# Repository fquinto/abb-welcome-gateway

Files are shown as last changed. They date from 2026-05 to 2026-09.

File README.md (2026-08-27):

# abb-welcome-gateway

ESP32-S3 gateway that connects an **ABB-Welcome / Busch-Welcome** 2-wire door
intercom to **Home Assistant**: doorbell notifications, remote door opening and
diagnostics, powered directly from the intercom bus.

| Top | Bottom |
|---|---|
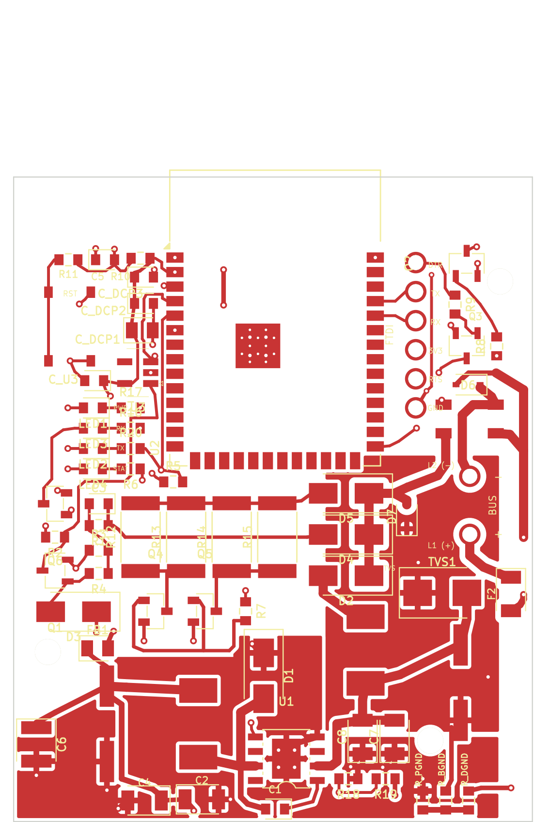
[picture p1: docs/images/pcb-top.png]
PCB top
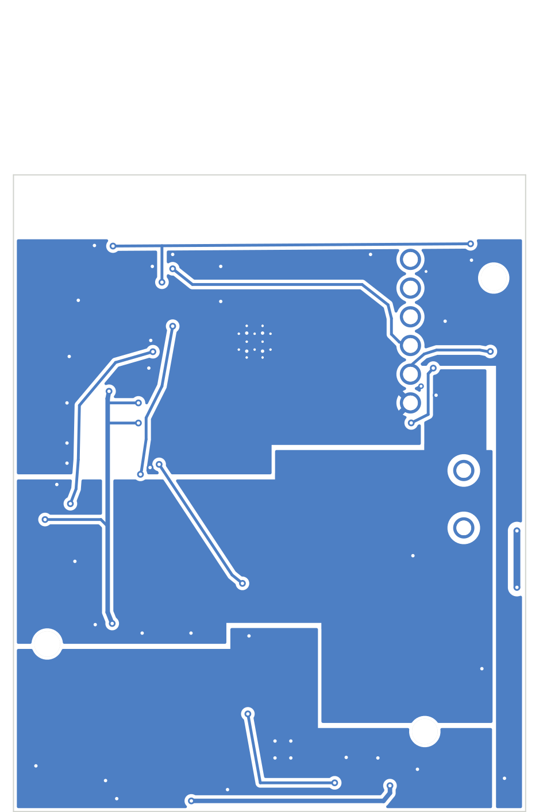
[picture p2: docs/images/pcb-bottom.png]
PCB bottom
|  |  |

## Highlights

- **Bus-powered**: TPS5430 buck converter runs the board from the ~28 V bus.
- **ESP32-S3-WROOM-1** with the antenna at the board edge and a proper copper
  keep-out.
- **Clean bus front-end**: filtered tap, TVS + reverse-polarity protection,
  polyfuse, Schmitt-buffered RX and open-drain TX drivers.
- **Three separated ground islands** (power / digital / bus) stitched at a
  single star point, so switching and RF return currents stay out of the bus
  reference.
- **ESPHome firmware**: native Home Assistant integration, OTA updates,
  YAML-only configuration for the end user.

## Repository layout

| Path | Contents |
|---|---|
| [`hardware/kicad-v3/`](hardware/kicad-v3/) | **The board** (KiCad 9): fully routed 2-layer PCB, DRC-clean. Source of truth for the hardware. |
| [`firmware/esphome/`](firmware/esphome/) | ESPHome configuration + `abb_welcome` custom component. |
| [`docs/`](docs/) | [Status](docs/STATUS.md) · [Pending tasks](docs/TODO.md) · [User guide](docs/user-guide.md). |
| [`legacy/`](legacy/) | Frozen design history: original EasyEDA v2 design, the tscircuit schematic capture of v3 and the conversion tooling. |

## Status

- **Hardware**: v3.0 design finished and fully routed; pre-fabrication
  verification pending (details in [docs/STATUS.md](docs/STATUS.md)).
- **Firmware**: ESPHome skeleton in place; ABB-Welcome bus protocol in
  development ([docs/TODO.md](docs/TODO.md)).

## Getting started

See the [user guide](docs/user-guide.md) for wiring, first flash over the
FTDI header and Home Assistant setup.

For hardware development: open `hardware/kicad-v3/abb-welcome-gateway-v3.kicad_pro`
in KiCad 9. Design rules, net classes and the ground-island scheme are described
in [`hardware/kicad-v3/README.md`](hardware/kicad-v3/README.md).

## Community & discussion

Questions, ideas or want to share your build? Join the discussion on Telegram:



## Donations for software development

If this project is useful to you, you can support its development:



Thank you for collaborating and helping the development of software improvements.

## Credits & license

The hardware derives from the original bus interface design by **mat931**.
Hardware is licensed under **CERN-OHL-W v2** (see [`LICENSE`](LICENSE));
the full design history is preserved in [`legacy/`](legacy/) and in the git log.

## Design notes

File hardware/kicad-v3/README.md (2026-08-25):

# KiCad v3 — routing target

KiCad project exported from the tscircuit v3 design (`legacy/tscircuit/index.circuit.tsx`)
so the board can be **routed in KiCad** (tscircuit's autorouter does not converge
on this board and produces no copper pours, which this design needs — three GND
islands, an RF module, the buck power stage and the 28 V bus all want planes /
poured copper, not point-to-point traces).

## Files

- `abb-welcome-gateway-v3.kicad_pro` — project (open this in KiCad).
- `abb-welcome-gateway-v3.kicad_pcb` — board: **fully routed** (traces, vias,
  the three GND island pours and stitching). `kicad-cli pcb drc`: 0 errors,
  0 unconnected items.
- `abb-welcome-gateway-v3.kicad_sch` — schematic.

Generated with `circuit-json-to-kicad` (KiCad file format `20241229`, i.e. KiCad 8/9).

## Source-of-truth note

Routing has started (and finished) here, so **this KiCad project is now the
source of truth for the PCB**. The tscircuit side (`legacy/tscircuit/index.circuit.tsx`)
is frozen as schematic reference; it does NOT reflect the physical changes below.

### Divergences from the tscircuit source (v3.0 routed)

- **U2 footprint replaced**: the tscircuit wrapper's hand-made 61-pad QFN-style
  footprint is not the real module. U2 now uses KiCad's official
  `RF_Module:ESP32-S3-WROOM-1` (41 pads + EP), antenna flush with the top board
  edge, with its copper keep-out.
- **LED_PIN moved from GPIO2 to GPIO6** (module pin 38 -> pin 6): the status
  LED net could not be routed out of the P2/FTDI quadrant. **Firmware must
  drive the status LED on GPIO6, not GPIO2.**
- **Board grown to 45.4 x 56.4 mm** (+3 mm height) to fit the buck band.
- Placement reworked by ground island (DGND top / BUS_GND middle+bus entry /
  PGND bottom): U1 rotated 180 (VIN toward C7/C8, SW toward D1/L2), feedback
  divider at the FB pin, star point (R_PGND/R_BGND/R_DGND) bottom-right,
  C4/C6 moved into the PGND island, LEDs rotated 180 (cathodes west), R5 and
  R8 relocated, TVS1 next to C23.
- Several nets use short B.Cu jogs; the DGND plane keeps deliberate bridges
  (module strip, east region) — re-run the zone fill after any edit.

## Regenerating (before any manual routing)

The export is driven by `@tscircuit/eval` → `circuit-json-to-kicad`. On a machine
where the tscircuit CLI runs (it needs the platform-native `@resvg/resvg-js`
binary), the supported one-liner is:

```bash
cd output
npx tsci export -f kicad_pcb index.circuit.tsx     # or: -f kicad_zip for the whole project
```

(These files were produced via the library path because the CLI's resvg binary
wasn't available in the generating environment; `tsci export` is the canonical way.)

## Routing checklist for this board

- Pour **separate ground regions** for `PGND` / `DGND` / `BUS_GND`; tie them only at
  the star point via R_PGND / R_DGND / R_BGND (the 0 Ω links).
- Keep the ESP32-S3 **antenna keep-out** clear (no copper under/near the antenna).
- Wide traces / short loops on the **buck power stage** (BUS_PWR, SW_NODE, PGND, L2, C2).
- **HV clearance** on the 28 V bus front-end (P1, F2, L1, D2/D4/D5/D7, TVS1).

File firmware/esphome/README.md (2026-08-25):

# Firmware (ESPHome)

- `abb-welcome-gateway.yaml` — device configuration. Copy
  `secrets.yaml.example` to `secrets.yaml`, fill in your credentials, edit the
  `substitutions` (bus addresses) and the door-open `data` payload for your
  installation, then run `esphome run abb-welcome-gateway.yaml`.

## How it works

The ABB-Welcome / Busch-Welcome protocol is implemented natively by ESPHome
(the `abbwelcome` remote protocol in `remote_base`, since 2024.4.0), so this
project needs **no custom protocol code**:

- `remote_receiver` on GPIO4 with `dump: [abbwelcome]` decodes bus frames; the
  `on_abbwelcome` automation fires the doorbell `binary_sensor` on a call.
- `remote_transmitter` on GPIO5 sends the door-open frame via
  `remote_transmitter.transmit_abbwelcome`.
- The status LED (GPIO6) is driven by ESPHome's `status_led` component.

See [`../../docs/protocol.md`](../../docs/protocol.md) for the protocol and
[`../../docs/user-guide.md`](../../docs/user-guide.md) for discovering your
addresses and the door-opener secret.

## To confirm on hardware

The RX front-end ends in a Schmitt inverter (74LVC1G14) and TX is open-drain,
so the net logic polarity is not certain from the schematic. If frames don't
decode or the door doesn't open, try `inverted: true` on the receiver and/or
transmitter pin. Tracked in [`../../docs/TODO.md`](../../docs/TODO.md).

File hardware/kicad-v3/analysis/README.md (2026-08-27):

# Pre-fabrication analysis

Numerical checks for the two open items in
[`docs/STATUS.md`](../../../docs/STATUS.md) → *To verify before fabrication*:

1. **Buck control loop** with `L2 = 100 µH` and ~590 µF of bulk — is it stable
   and fast enough?
2. **TVS1 (SMBJ30A) clamp** versus the TPS5430's 36 V VIN absolute maximum.

These are **models to guide the bench measurement, not a replacement for it.**
Absolute phase-margin numbers carry roughly ±15° of modelling/tolerance
uncertainty; the *trends* are what matter.

## Run

```sh
python3 buck_loop_analysis.py   # prints margins table + writes tps5430_bode.png
python3 tvs_clamp.py            # prints TVS clamp vs surge current
```

Requires `numpy`, `scipy`, `matplotlib`.

---

## 1. Buck loop stability

**Model.** The TPS5430 is a voltage-mode buck with a *fixed internal type-III*
compensation network whose transfer function is published in the datasheet
(SLVS632, Eq. 15): zeros at 2170 / 2590 Hz, poles at 2165 Hz (integrator),
24 k, 54 k, 440 kHz. We combine it with the power stage built from the **real
output-cap network** (C19 470 µF Al, C6 100 µF Ta, C2/C4 10 µF Ta — each as
`ESR + 1/sC` in parallel) and calibrate the one unknown constant (the
feed-forward modulator gain `VIN/Vramp`) so the datasheet's own worked example
(5 V, 15 µH, 220 µF, 40 mΩ) crosses 0 dB at 18 kHz. Calibrated value ≈ **22.9**,
which is physically sensible for this part.

**Result (nominal, C19 ESR = 0.10 Ω, 0.3 A load):**

| Metric | Value |
|---|---|
| Crossover `fCO` | **≈ 3.2 kHz** |
| Phase margin | **≈ 70°** |
| Gain margin | **≈ 36 dB** |
| Load-step 0.3 A | ~27 mV dip, ~0.6 ms recovery |

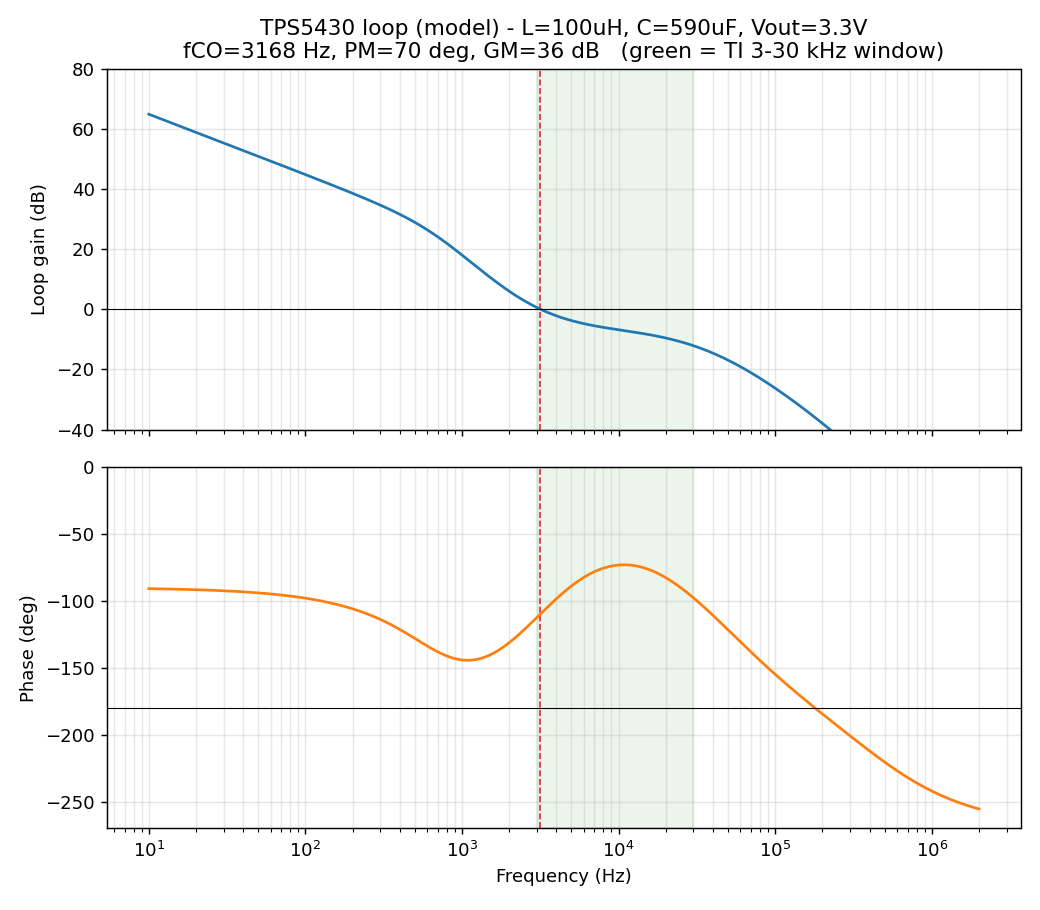
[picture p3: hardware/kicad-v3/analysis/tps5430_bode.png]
Bode plot


**Why this refines the STATUS.md note.** The note estimated `fCO ≈ 1.5 kHz`
(from TI's Eq. 7, `fLC²/85·VOUT`) and worried it sat *below* TI's 3–30 kHz
window — sluggish and marginal. Eq. 7 is **pessimistic here because it assumes a
low-ESR output cap**. In reality the aluminium electrolytic's ESR zero
(≈ 3.4 kHz) sits inside the loop, lifts the gain and, together with the internal
type-III zeros at 2.2 / 2.6 kHz, pushes the crossover **up to ~3.2 kHz — the
bottom edge of TI's window — with a healthy ~70° phase margin.** The note's
instinct ("stable thanks to the ESR") is correct; the "marginal" part is not.

**Robustness.** Stable across the whole plausible electrolytic ESR range and load:

| C19 ESR (Ω) | 0.05 | 0.08 | 0.10 | 0.12 | 0.15 | 0.20 |
|---|---|---|---|---|---|---|
| Phase margin | 48° | 62° | 70° | 79° | 90° | 106° |

Phase margin *increases* with ESR, and the worst case (fresh/warm cap, ESR ≈
0.05 Ω) still gives ~48°. Load current 0.1–2 A holds ~70°. So the design is
comfortably stable in the model.

**Confirmed warning — do NOT swap the bulk for low-ESR ceramics.** Removing the
ESR zero collapses the phase margin from ~70° to **~19°** (ringy / marginal):

| Output bulk | fCO | Phase margin |
|---|---|---|
| 590 µF electrolytic/Ta (as designed) | 3.2 kHz | **70°** |
| 590 µF low-ESR ceramic | 2.6 kHz | **19°** ⚠ |

Keep C19/C6/C2/C4 as specified, or add an external compensation network first.

**Bench check on the first board:** loop is *predicted* fine, but the crossover
is set by the electrolytic ESR (drifts with temperature/age). Confirm with a
load-step (look for clean recovery ~0.5 ms, no sustained ringing) or, better, an
injected-signal Bode. Expect crossover ~3 kHz and no gain peaking.

---

## 2. TVS1 clamp vs buck VIN abs-max

**Model.** Piecewise-linear TVS, `Vclamp(I) = VBR + I·Rdyn`. SMBJ30A datasheet
points: `VWM = 30 V`, `VBR(min) = 33.3 V`, `VC = 48.4 V @ IPP = 12.4 A`
→ `Rdyn ≈ 1.22 Ω`.

| TVS current | Clamp voltage | vs 36 V abs-max |
|---|---|---|
| 0.5 A | 33.9 V | OK |
| 1 A | 34.5 V | OK |
| **2.2 A** | **36.0 V** | = abs-max |
| 5 A | 39.4 V | over |
| 12.4 A | 48.4 V | over |

**Reading.** At the 28 V bus nominal the 30 V standoff means no conduction, and
clamping only starts above ~33 V — good. The buck's 36 V abs-max is exceeded
only once the TVS conducts **more than ~2.2 A**. Two mitigations decide whether
that matters:

- **Fast transients (ESD / inductive spikes): covered.** `L3 = 100 µH` in
  series plus the input caps isolate the buck VIN node — the buck never sees the
  fast edge, so the clamp voltage at the bus side is not what reaches it.
- **Slow, sustained high-current overvoltage: residual gap.** L3 has no
  impedance at DC, so a slow fault that drives >2.2 A into the TVS can pull the
  buck VIN above 36 V while the TVS clamps at up to 48 V.

For a 28 V low-voltage intercom bus a high-energy surge is unlikely, so the
practical risk is low. For guaranteed protection (belt-and-suspenders):

- **Relocate TVS1 to the buck VIN node (downstream of L3)** — near-free board
  revision, clamps the node the buck actually sees; or
- use a **40–60 V-rated buck** (e.g. TPS54360, LMR14030) for unconditional VIN
  headroom.

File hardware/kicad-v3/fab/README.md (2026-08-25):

# Fabrication outputs

Generated from `abb-welcome-gateway-v3.kicad_pcb` with `kicad-cli` (KiCad 9).
Regenerate with the commands at the bottom after any board change.

## Files

| File | Purpose |
|---|---|
| `abb-welcome-gateway-v3-gerbers.zip` | Gerbers (RS-274X) + Excellon drill — upload this to the fab house. |
| `gerbers/` | The individual layers, unzipped. |
| `abb-welcome-gateway-v3-BOM.csv` | Bill of materials (grouped). |
| `abb-welcome-gateway-v3-pos.csv` | Pick-and-place / centroid (both sides, drill-file origin). |

## Board parameters

- **Layers**: 2 (signal + poured grounds).
- **Size**: 45.4 × 56.4 mm.
- **Min track / clearance**: 0.2 mm. **Min via**: 0.6 mm / 0.3 mm drill.
- **Copper**: 1 oz suggested. Finish HASL or ENIG (ENIG preferred for the
  fine-pitch module and the QFN-style TPS5430 thermal pad).
- All components are on the **top** side; the bottom is ground pours only.

## BOM notes

- The `LCSC` column carries the part numbers defined in the design. Entries left
  blank are **generic passives** (0603 resistors/capacitors, the ferrite bead,
  the FTDI header) — assign an LCSC basic part by value + package in the
  assembly tool. They are intentionally not guessed here to avoid fitting the
  wrong part.
- **Through-hole parts** (`P1` screw terminal, `P2` FTDI header) are not covered
  by standard SMT assembly — hand-solder them or request THT assembly.
- Three tooling/mounting holes are NPTH (no BOM line).

## Regenerating

```bash
cd hardware/kicad-v3
PCB=abb-welcome-gateway-v3.kicad_pcb

kicad-cli pcb export gerbers --output fab/gerbers/ \
  --layers "F.Cu,B.Cu,F.Paste,B.Paste,F.SilkS,B.SilkS,F.Mask,B.Mask,Edge.Cuts" \
  --no-protel-ext "$PCB"
kicad-cli pcb export drill --output fab/gerbers/ --format excellon \
  --drill-origin absolute --excellon-units mm --generate-map --map-format gerberx2 "$PCB"
kicad-cli pcb export pos --output fab/abb-welcome-gateway-v3-pos.csv \
  --format csv --units mm --side both --use-drill-file-origin "$PCB"
( cd fab && zip -j abb-welcome-gateway-v3-gerbers.zip gerbers/*.gbr gerbers/*.drl gerbers/*.gbrjob )
```

The BOM is built by `tools`-free script logic (see the project history); for a
quick refresh from the schematic instead:
`kicad-cli sch export bom --group-by Value --output fab/BOM.csv abb-welcome-gateway-v3.kicad_sch`.

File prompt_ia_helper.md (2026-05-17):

Always create tscircuit code inside of an HTML canvas (use a tool)

Do not import any components! Just use the builtin tscircuit elements (described below)

Make sure to create a script tag with from the source "https://unpkg.com/@tscircuit/circuit-preview@latest/dist/index.global.js" and a script tag with type="text/babel" that contains the window.tscircuit.render function call.

<html>
  <head>
    <script src="https://unpkg.com/@tscircuit/circuit-preview@latest/dist/index.global.js"></script>
    <script type="text/babel">
      window.tscircuit.render(
        <board pcbPack>
          <chip
            name="U1"
            footprint="soic8"
            pinLabels={{
              pin1: "GND",
              pin2: "TRIG",
              pin3: "OUT",
              pin4: "RESET",
              pin5: "CTRL",
              pin6: "THRES",
              pin7: "DISCH",
              pin8: "VCC",
            }}
            schPinArrangement={{
              leftSide:  { direction: "top-to-bottom", pins: ["RESET","CTRL","THRES","TRIG"] },
              rightSide: { direction: "top-to-bottom", pins: ["VCC","OUT","DISCH","GND"] },
            }}
          />
          <resistor  name="R1" resistance="1k"    footprint="0805" />
          <resistor  name="R2" resistance="10k"   footprint="0805" />
          <capacitor name="C1" capacitance="10uF" footprint="1206" />
          <capacitor name="C2" capacitance="0.01uF" footprint="0805" />
          <led       name="D1" color="red" footprint="led0603" />
          <resistor  name="R3" resistance="330" footprint="0805" />
          <trace from="U1.VCC"   to="net.VCC" />
          <trace from="U1.GND"   to="net.GND" />
          <trace from="U1.RESET" to="net.VCC" />
          <trace from="U1.CTRL"  to="C2.pin1" />
          <trace from="C2.pin2"  to="net.GND" />
          <trace from="U1.THRES" to="U1.TRIG" />
          <trace from="net.VCC"  to="R1.pin1" />
          <trace from="R1.pin2"  to="U1.DISCH" />
          <trace from="U1.DISCH" to="R2.pin1" />
          <trace from="R2.pin2"  to="U1.THRES" />
          <trace from="U1.THRES" to="C1.pin1" />
          <trace from="C1.pin2"  to="net.GND" />
          <trace from="U1.OUT"   to="R3.pin1" />
          <trace from="R3.pin2"  to="D1.pin1" />
          <trace from="D1.pin2"  to="net.GND" />
        </board>
      )
    </script>
  </head>
  <body></body>
</html>

Here's a quick primer on how to use tscircuit:

## Core `<chip />` props (most-used)

* `name`: reference designator (e.g., `"U1"`).
* `footprint`: **string** (e.g., `"soic8"`/`"0402"`) **or** a `<footprint />` element.
* `pinLabels`: map pad → pin label (e.g., `{ pin1: "VCC", pin5: "GND" }`).
* `schPinArrangement`: control schematic sides/order of pins (alias **`schPortArrangement`** is deprecated).
  Optional styling/box props: `schPinStyle`, `schPinSpacing`, `schWidth`, `schHeight`. ([GitHub][3])
* Connectivity helpers:
  `internallyConnectedPins`, `externallyConnectedPins`, and **`connections`** (auto‑traces by pin label)
* Extras: `pcbPinLabels`, `cadModel`, `noSchematicRepresentation`

---

## Minimal chip

<chip
  name="U1"
  footprint="soic8"
  pinLabels={{ pin1: "VCC", pin2: "DISCH", pin3: "THRES", pin4: "CTRL",
               pin5: "GND", pin6: "TRIG", pin7: "OUT", pin8: "RESET" }}
/>

## Arrange pins on schematic (+ style/size)

<chip
  name="U1" footprint="soic8" pinLabels={{ pin1:"VCC", pin5:"GND", pin7:"OUT", pin8:"RESET" }}
  schPinArrangement={{
    leftSide:  { direction: "top-to-bottom",    pins: ["VCC"] },
    rightSide: { direction: "bottom-to-top",    pins: ["GND","OUT","RESET"] },
    topSide:   { direction: "left-to-right",    pins: [] },
    bottomSide:{ direction: "left-to-right",    pins: [] },
  }}
  schPinStyle={{ GND: { topMargin: "0.5mm" } }}
  schPinSpacing={0.75} schWidth="12mm"
/>

## Custom PCB footprint (inline)

<chip
  name="U1"
  footprint={
    <footprint>
      <smtpad portHints={["1"]} pcbX="-1mm" pcbY="0" width="1mm" height="0.7mm" />
      <smtpad portHints={["2"]} pcbX="1mm"  pcbY="0" width="1mm" height="0.7mm" />
    </footprint>
  }
/>

## Internally / externally shorted pins

<chip
  name="SW1" footprint="pushbutton"
  internallyConnectedPins={[["pin1","pin4"],["pin2","pin3"]]}
/>

<chip
  name="U1" footprint="soic8" pinLabels={{ pin1:"VCC", pin5:"GND", pin6:"TRIG", pin2:"DISCH" }}
  externallyConnectedPins={[["GND","DISCH"],["TRIG","VCC"]]}
/>

## Auto‑connect with `connections`

A more condensed alternative to `<trace />`, available on basically all elements

<chip
  name="U1" footprint="soic8" pinLabels={{ pin1:"VCC", pin5:"GND", pin7:"OUT" }}
  connections={{ VCC: "net.V5", GND: "net.GND", OUT: "net.SIGNAL" }}
/>

Use with `sel` for type‑safe selectors (e.g., `OUT: sel.U2(MyReg).VOUT`). ([GitHub][3], [docs.tscircuit.com][4])

## Part selection & PCB labels

<chip
  name="U1" footprint="soic8"
  supplierPartNumbers={{ jlcpcb: ["C57759"] }}
  manufacturerPartNumber="SN74HC14DR"
  pcbPinLabels={{ "1":"TX", "2":"RX" }}
/>

## All normal elements and important props

Most elements have a `name` and `footprint` prop. Most properties
are optional.

- `<board />` - root element
- `<group />` - group of elements
- `<chip name="U1" pinLabels={{ pin1: "VCC", ... }} />` - any generic chip
- `<resistor name="R1" resistance="1k" footprint="0402" />` - `resistance`
- `<capacitor name="C1" capacitance="100n" footprint="0402" />` - `capacitance`
- `<inductor name="L1" inductance="100n" footprint="0402" />` - `inductance`
- `<led name="LED1" color="red" />` - `color`
- `<diode name="D1" variant="standard" />` - `variant` (standard/schottky/zener/avalanche/photo/tvs)
- `<trace from="U1.VCC" to="R1.pin1" />` - `from`, `to`
- `<transistor name="Q1" type="npn" />` - `type` (npn/pnp/nmos/pmos)
- `<mosfet name="M1" channelType="n" mosfetMode="enhancement" />` - `channelType` (n/p), `mosfetMode` (enhancement/depletion)
- `<hole name="H1" diameter="1mm" />` - `diameter`
- `<testpoint name="TP1" />` - `padShape` (circle/rect), `padDiameter`, `footprintVariant` (smd/through_hole), `width`, `height`
- `<via />` - `holeDiameter`, `outerDiameter`
- `<switch />` - `spdt` (bool), `dpdt` (bool), `spst` (bool), `spdt` (bool), `isNormallyClosed`
- `<pinheader />` - `pinCount`, `schFacingDirection` (left, up, right, down), `schPinArrangement`, `gender` (male/female/unpopulated), `showSilkscreenPinLabels`, `holeDiameter`, `connections`, `pinLabels`, `rightAngle`, `doubleRow`
- `<jumper name="J1" pinCount={2} pinLabels={{ pin1: "A", pin2: "B" }} />` - similar to pinheader but pin count must be 2 or 3
- `<fuse name="F1" currentRating="1A" voltageRating="250V" />`
- `<pushbutton name="SW1" />`
- `<cutout shape="rect" width="1mm" height="1mm" />` - `shape` (rect), `width`, `height`
- `<crystal name="X1" frequency="10MHz" />` - `frequency`, `loadCapacitance`, `loadResistance`
- `<battery name="BAT1" />` - `capacity`, `voltage`
- `<potentiometer name="P1" maxResistance="10k" pinVariant="two_pin" />` - `maxResistance`, `pinVariant` (two_pin/three_pin). Common footprint "pinrow2"/"pinrow3"

### Footprint Only Elements

- `<smtpad />` - `portHints`, `pcbX`, `pcbY`, `shape`, `width`, `height`
- `<platedhole />` - `pcbX`, `pcbY`, `shape`, `width`, `height`

## Common Footprints

- "0402", "0603", "0805", "1206", "1210"
- "dip", "dip8", "dip16", "axial", "soic8", "bga64", "tssop8", "stampboard", "stampreceiver", "hc49", "to92", "to220", "ssop", "qfp16", "qfn16", "sot23", "sot23_5", "sot223", "pinrow2", "pinrow6"
- You can generally alter footprints by changing numbers or adding parameters e.g. "soic8_w4mm" creates a 4mm width soic, "pinrow8_p1mm" creates an 8 pin pinrow with 1mm pitch
- For batteries, just use "pinrow2"

## Selector Syntax

When specifying a selector, use "{component_name}.{pin_name}" or "net.{net_name}"

These are common selectors:
- "U1.VCC","R1.pin1","C1.pin2","C1.pos","U2.GND", "J1.SOME_PIN_LABEL"
- Special case Net Selectors: "net.VCC","net.GND","net.GPIO1", "net.BAT_PLUS", "net.BAT_MINUS"

Selectors are used in the `connections` prop and the `from` and `to` props of the `<trace />` element.

- `<trace from="U1.VCC" to="R1.pin1" />`
- `<chip name="U1" connections={{ VCC: "net.VCC", GND: "net.GND" }} />`

## Important Notes

- Make sure you've connected both sides of every passives (resistor, capacitor, inductor)
  with a <trace /> or a connections={{ pin1: ..., pin2: ... }} prop
- Every normal element has a footprint prop

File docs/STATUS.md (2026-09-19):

# Project status

_Last updated: 2026-08-25_

## Hardware — v3.0, routed, pre-fabrication

The KiCad project in [`hardware/kicad-v3/`](../hardware/kicad-v3/) is the source of
truth for the board. Current state:

- **Schematic-level design complete** (captured and reviewed in the legacy
  tscircuit project, then exported to KiCad).
- **Placement and routing complete**: three separated ground islands
  (`PGND` / `DGND` / `BUS_GND`) as copper pours stitched at a single star point,
  antenna keep-out honoured, HV clearance class (0.5 mm) on the 28 V bus nets.
- **DRC clean**: 0 errors, 0 unconnected items (`kicad-cli pcb drc`, KiCad 9).
- Board size 45.4 × 56.4 mm, 2 layers, min track/clearance 0.2 mm
  (standard JLCPCB/PCBWay capability).

### What v3 improves over the original v2 design

- **ESP32-S3-WROOM-1** module replaces the EOL ESP32-SOLO-1 (official KiCad
  footprint, antenna flush with the board edge).
- **74LVC1G14 Schmitt buffer** isolates the doorbell bus from the ESP32 GPIO.
- **Ferrite bead + local decoupling** split the buck output `V3V3` from the
  module-local rail `V3V3_ESP` to keep switching noise out of the radio.
- **Three ground islands** joined only at a star point (0 Ω links
  `R_PGND` / `R_DGND` / `R_BGND`) so power-stage and RF return currents stay out
  of the bus reference.
- Bus TVS (SMBJ30A), reverse-polarity protection, polyfuse, and a fully
  reworked bus front-end (all connectivity bugs of the conversion fixed).

### To verify before fabrication

- **L2 = 100 µH output inductor — in spec, at the top of the range, modelled
  stable.** The TPS5430 datasheet allows 10–100 µH. A loop model calibrated to
  TI's own worked example (see [`hardware/kicad-v3/analysis/`](../hardware/kicad-v3/analysis/))
  puts the crossover at **~3.2 kHz** (bottom edge of TI's 3–30 kHz window) with
  **~70° phase margin** — the aluminium electrolytic ESR zero lifts the crossover
  above the LC-only estimate. Stable across the plausible ESR range (48–106°) and
  load. Do **not** swap C19/C6/C2/C4 for low-ESR ceramics: the model shows phase
  margin collapsing to ~19° (ringy) without the ESR zero. A bench load-step /
  Bode measurement is still recommended before a production run to confirm the
  crossover against the real electrolytic ESR.
- **TVS1 clamp vs buck abs-max.** SMBJ30A clamps at ~48 V at full surge, above
  the TPS5430's 36 V abs-max VIN. Analysis ([`analysis/tvs_clamp.py`](../hardware/kicad-v3/analysis/tvs_clamp.py))
  shows the buck VIN only exceeds 36 V once the TVS conducts **> ~2.2 A**; L3 +
  input caps cover fast transients, leaving a slow high-current overvoltage as
  the residual gap (low probability on a 28 V bus). For tighter protection move
  the clamp to the buck VIN node (after L3) or use a higher-VIN buck.

### Optional hardening

- `C_DCP1` = 22 µF in 0805: heavy DC-bias derating — consider 1206 or
  2 × 10 µF 0805.
- No dedicated BOOT button (GPIO0 is only driven by the FTDI auto-program
  circuit). A tactile to ground on GPIO0 would help if auto-program ever fails.

### BOM parts made explicit (raised in the first fab quote — resolved)

Two designators carried generic placeholders from the tscircuit → KiCad
conversion. The exact orderable parts are now set in the symbol/footprint, BOM
and pos files, and the fab house confirmed both in the updated quote
(2026-09-04, "It's updated, pls confirm."):

- **P2 — 6-pin serial/programming header.** Exported with a generic `chip`
  footprint and empty value, but the copper is a real **1×6 through-hole header,
  2.54 mm pitch** (drill 1.3 mm) with the FTDI pinout GND / RTS / V3V3_ESP / RX /
  TX / DTR. Assembled as a **1×6 2.54 mm straight male pin header**,
  **Würth 61300611121** — footprint/value now `PinHeader_1x06_2.54mm` /
  `61300611121` so it no longer exports blank.
- **U3 — 74LVC1G14 full part number.** The PCB footprint is 5-pad SMD at 0.95 mm
  pitch, i.e. **SOT-23-5**, so the orderable part is **SN74LVC1G14DBVR**
  (SOT-23-5), *not* the SC-70/SOT-353 `DCK`/`GW` variant (0.65 mm pitch, wrong
  footprint). Full MPN now set in the BOM field.

For the passives left with a blank LCSC, the fab picked equivalent 0603/0805
basic parts on its own (no confirmation needed) — including higher-voltage caps
for `C_DCP1/2/3`/`C_U3` and an hFE-graded `S8050 J3Y` for `Q1–Q3`.

### First-article assembly review (5 units, 2026-09)

The fab assembled 5 units (SMD soldered, THT `P1`/`P2` tacked then trimmed on
ship) and asked us to confirm polarised parts, flagging the two electrolytic
cans `C19` and `C23`:

- **`C19`** (470 µF/16 V, RVT, buck 3V3 output) — measured OK, correct
  orientation. `+` = `V3V3`, `−` = `PGND`.
- **`C23`** (100 µF/50 V, VEJ, ~28 V bus rail) — the fab could not measure its
  polarity because **it has no continuity to the bus terminal `P1` by design**:
  `C23` sits on the *rectified/protected* rail, downstream of the input
  rectifier, fuse `F2` and TVS `SMBJ30A`. Marked for them by adjacency —
  `+` (`BUS_PWR`) = pad toward `F2`/`SMBJ30A`/`P1`; `−` (`BUS_GND`) = pad toward
  the `R_PGND`/`R_DGND`/`R_BGND` star-point resistors.

Root cause of the ambiguity: the `C19`/`C23` footprints (from the tscircuit →
KiCad conversion) carry **no silkscreen polarity mark**. Fix for **v3.1**: add a
`+` silk indicator next to the positive pad of `C19`/`C23` (and the polarised
tantalums), so orientation no longer depends on measurement.

### Divergences from the legacy schematic capture

The routed PCB diverges from `legacy/tscircuit/index.circuit.tsx` in a few
physical aspects (real module footprint, board height, per-island placement,
**status LED moved to GPIO6**). The authoritative list lives in
[`hardware/kicad-v3/README.md`](../hardware/kicad-v3/README.md).

## Firmware — configured, pending hardware validation

[`firmware/esphome/`](../firmware/esphome/) is an ESPHome configuration built on
ESPHome's **native `abbwelcome` protocol** (in `remote_base` since 2024.4.0), so
there is no custom protocol code to maintain. Pinout: bus RX = GPIO4,
bus TX = GPIO5, status LED = GPIO6.

- Doorbell (`binary_sensor` via `on_abbwelcome`), door opener (`button` via
  `transmit_abbwelcome`), status LED, WiFi/API/OTA: **done and compiling**.
- **Pending on real hardware**: confirm RX/TX logic polarity (the front-end
  has a Schmitt inverter and an open-drain TX stage — may need `inverted: true`),
  and discover the installation's bus addresses and door-opener secret from the
  logs. See [`TODO.md`](TODO.md) and [`protocol.md`](protocol.md).

## Documentation

- [`user-guide.md`](user-guide.md): wiring, first flash and Home Assistant
  setup (sections that depend on the protocol implementation are marked as
  pending).

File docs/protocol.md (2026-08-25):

# ABB-Welcome / Busch-Welcome bus protocol

Notes on the 2-wire bus protocol used by the intercom, and how this project
talks to it.

> **Key point**: ESPHome already implements this protocol natively as the
> `abbwelcome` remote-transmitter/receiver protocol (in `remote_base`, since
> ESPHome 2024.4.0, contributed by mat931). This project uses that
> implementation rather than re-decoding the waveform by hand — see
> [Firmware approach](#firmware-approach) below.

## Physical layer

- Single differential-ish 2-wire bus carrying ~28 V DC with data superimposed.
- The board taps it, filters it and produces a clean 0–3.3 V digital RX
  (`BUS_RX_DIG`, Schmitt-buffered) into the ESP32, and drives the bus with an
  open-drain transistor stage from a TX GPIO.

## Line coding (as implemented by ESPHome `abbwelcome`)

Pulse-distance style coding, MSB first, timings in microseconds:

| Symbol | Encoding |
|---|---|
| Bit period | `102 µs` (`BIT_ONE_SPACE_US`) |
| Bit `0` | mark `32 µs` (`BIT_ZERO_MARK_US`, accepted range 18–44) + space `70 µs` (`102 − 32`) |
| Bit `1` | no mark; the space is extended by another `102 µs` |
| Inter-byte gap | `210 µs` (`BYTE_SPACE_US`) |

Each byte starts with a mark; `0` bits insert a mark/space transition, `1` bits
just lengthen the preceding space. A frame begins with the sync bytes
`0x55 0xFF`.

## Frame format

Internal buffer layout (`std::array`, up to `12 + 15` bytes):

| Bytes | Field |
|---|---|
| 0–1 | Sync `0x55 0xFF` |
| 2 | Flags: retransmission bit, address-length bit (`0x40` → 3-byte addresses), data-length (`& 0x3F`, max 15) |
| 3 | Message type |
| 4… | Destination address, source address (2 or 3 bytes each), message ID, payload, checksum |

- `three_byte_address` selects 2- vs 3-byte addressing; some installations use
  6-hex-digit addresses.
- **Checksum**: XOR-accumulate over all bytes except the last, with a fixed
  bit-mixing step per byte, finalized as `(temp & 0xFE) ^ ((temp >> 8) & 1)`
  and inverted. Frames failing the checksum are rejected on RX.

## Message types

| Type | Meaning |
|---|---|
| `0x01` | Outdoor station → indoor station (call) |
| `0x11` | Indoor station message (indoor doorbell) |
| `0x0A` | Outdoor station → gateway |
| `0x0D` / `0x0E` | Door-unlock command |
| `0x81` | Reply to `0x01` |
| `0x8D` / `0x8E` | Door-opener response |
| `0x91` | Reply to `0x11` |

Types `≥ 0x80` are replies to the corresponding request.

## Addresses

Installation-specific; discover yours by watching the bus (`dump: [abbwelcome]`
in ESPHome logs while using the intercom). Typical patterns:

| Device | Address |
|---|---|
| Indoor station | `0x10XX` (or `0x0001XX` on 3-byte systems) |
| Outdoor station | `0x2001` |
| Gateway | `0x3001` |
| Door lock | `0x4001` |

The last two hex digits are the apartment number.

## Door open

The unlock command is a message (type `0x0D`) to the door-lock address carrying
a system-specific **secret data payload**. There is no universal value: capture
a real door-open event on your installation (or find it by trial), then send
the same `data` bytes. Example from a working install:
`source 0x1001 → dest 0x4001, type 0x0D, data [0xAB, 0xCD, 0xEF]`.

## Firmware approach

Because ESPHome ships the protocol, the firmware does **not** implement a custom
decoder. It uses:

- `remote_receiver` on the bus-RX GPIO with `dump: [abbwelcome]` and an
  `on_abbwelcome` trigger to react to incoming frames.
- `remote_transmitter` on the bus-TX GPIO to send the door-open frame via a
  `remote_transmitter.transmit_abbwelcome` action.

See [`firmware/esphome/abb-welcome-gateway.yaml`](../firmware/esphome/abb-welcome-gateway.yaml).

## Sources

- ESP32 Doorbell Bus Interface by mat931 —
  <https://github.com/Mat931/esp32-doorbell-bus-interface>
- ESPHome `abbwelcome` remote protocol —
  `esphome/components/remote_base/abbwelcome_protocol.{h,cpp}`
- ESPHome device page —
  <https://devices.esphome.io/devices/doorbell-interface-for-abb-welcome/>

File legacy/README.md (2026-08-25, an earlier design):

# Legacy — frozen design history

Everything in this folder belongs to earlier stages of the project and is **frozen**:
it is kept for reference and licensing history, but it is no longer maintained and
does not describe the current board. The live design is the KiCad project in
[`../hardware/kicad-v3/`](../hardware/kicad-v3/) and the firmware in
[`../firmware/`](../firmware/).

## Contents

| Folder | What it is |
|---|---|
| `easyeda-v2/` | The original v2 hardware design (EasyEDA JSON, BOM, netlist, SVG). Derived from work by **mat931**, licensed CERN-OHL-W v2. Open the JSON files in the EasyEDA editor (web or Pro). |
| `tools/` | A Node/JS pipeline that converted the EasyEDA JSON into `circuit-json` and scaffolded the tscircuit project. Run from inside `tools/` (`npm install`, then `npm run convert`). Paths are relative to this `legacy/` folder. |
| `tscircuit/` | The tscircuit (React/TSX) project where the v3 schematic was captured and reviewed (`index.circuit.tsx` + per-chip wrappers). This was the design source of truth until the export to KiCad; the routed PCB has since diverged (see `../hardware/kicad-v3/README.md` for the list of physical divergences). |
| `samples/` | Reference tscircuit projects and sample JSONs used while developing the converter. |
| `tscircuit-primer.md` | A quick tscircuit syntax primer used while hand-editing `tscircuit/index.circuit.tsx`. |

## Why it is kept

- The EasyEDA v2 files are the upstream design this project derives from
  (CERN-OHL-W v2 requires making the source available).
- The tscircuit project documents every schematic-level decision of v3.0 and its
  design-review history.
- The converter tools may be useful to anyone doing a similar EasyEDA → tscircuit
  migration.

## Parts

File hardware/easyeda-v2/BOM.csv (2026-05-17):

ID | Name | Designator | Footprint | Quantity | Manufacturer Part | Manufacturer | Supplier | Supplier Part | Price | Pins
1 | 10nF | C1 | C0603 | 1 | 0603B103K500NT | FH(风华) | LCSC | C57112 | 0.003 | 2
2 | 10uF | C2,C4 | CAP-SMD_L3.2-W1.6-RD-C7171 | 2 | TAJA106K016RNJ | Kyocera AVX | LCSC | C7171 | 0.129 | 2
3 | 68nF | C3 | C0603 | 1 | CL10B683KB8NNNC | SAMSUNG(三星) | LCSC | C31658 | 0.01 | 2
4 | 100nF | C5 | C0603 | 1 | CC0603KRX7R9BB104 | YAGEO(国巨) | LCSC | C14663 | 0.003 | 2
5 | 100uF | C6 | CASE-B_3528 | 1 | TAJB107K006RNJ | Kyocera AVX | LCSC | C16133 | 0.479 | 2
6 | 2.2uF | C7,C8 | C1206 | 2 | CL31B225KBHNNNE | SAMSUNG(三星) | LCSC | C50254 | 0.04 | 2
7 | 470uF | C19 | CAP-SMD_BD8.0-L8.3-W8.3-LS9.0-FD | 1 | RVT470UF16V67RV0031 | KNSCHA(科尼盛) | LCSC | C2858857 | 0.087 | 2
8 | 100uF | C23 | CAP-SMD_BD8.0-L8.3-W8.3-RD | 1 | VEJ101M1HTR-0810 | Lelon | LCSC | C176665 | 0.108 | 2
9 | SS24 | D1,D2,D3,D4,D5 | SMA_L4.3-W2.6-LS5.0-FD | 5 | SS24 | 宏迦橙 | LCSC | C7420362 | 0.025 | 2
10 | SD36C_C502537 | D6,D7 | SOD-323_L1.7-W1.3-LS2.7-BI | 2 | SD36C | MDD | LCSC | C502537 | 0.042 | 2
11 | nSMD005 | F2 | F1206 | 1 | nSMD005 | TECHFUSE | LCSC | C70064 | 0.034 | 2
12 | ACT45B-510-2P-TL003 | L1 | IND-SMD_4P-L4.5-W3.2-TL | 1 | ACT45B-510-2P-TL003 | TDK | LCSC | C76584 | 0.318 | 4
13 | 100uH | L2,L3 | IND-SMD_L7.1-W6.6 | 2 | SMMS0650-101M | SXN(顺翔诺) | LCSC | C2894722 | 0.172 | 2
14 | Red | LED1 | LED0603-RD | 1 | KT-0603R | KENTO | LCSC | C2286 | 0.007 | 2
15 | Yellow | LED2,LED3 | LED0603-RD-YELLOW | 2 | 19-213/Y2C-CQ2R2L/3T(CY) | EVERLIGHT(亿光) | LCSC | C72038 | 0.023 | 2
16 | Blue | LED4 | LED0603-FD_BLUE | 1 | 19-217/BHC-ZL1M2RY/3T | EVERLIGHT(亿光) | LCSC | C72041 | 0.021 | 2
17 | WJ500V-5.08-2P-14-00A | P1 | CONN-TH_2P-P5.00_WJ500V-5.08-2P | 1 | WJ500V-5.08-2P | KANGNEX(康奈克斯电气) | LCSC | C8465 | 0.133 | 2
18 | S8050_C2146 | Q1,Q2,Q3 | SOT-23-3_L3.0-W1.7-P0.95-LS2.9-BR | 3 | S8050 J3Y | CJ(江苏长电/长晶) | LCSC | C2146 | 0.013 | 3
19 | 2N7002 | Q4,Q5,Q6 | SOT-23-3_L2.9-W1.3-P1.90-LS2.4-BR | 3 | 2N7002 | CJ(江苏长电/长晶) | LCSC | C8545 | 0.014 | 3
20 | 100kΩ | R1,R8,R9 | R0603 | 3 | 0603WAF1003T5E | UNI-ROYAL(厚声) | LCSC | C25803 | 0.002 | 2
21 | 10K | R2,R3,R10 | R0603 | 3 | 0603WAF1002T5E | UniOhm | LCSC | C25804 | 0.003 | 2
22 | 1kΩ | R4,R5,R6,R17 | R0603 | 4 | 0603WAF1001T5E | UNI-ROYAL(厚声) | LCSC | C21190 | 0.002 | 2
23 | 75Ω | R7 | R0603 | 1 | 0603WAF750JT5E | UNI-ROYAL(厚声) | LCSC | C4275 | 0.002 | 2
24 | 150Ω | R11,R16,R20 | R0603 | 3 | 0603WAF1500T5E | UNI-ROYAL(厚声) | LCSC | C22808 | 0.002 | 2
25 | 820Ω | R12,R13,R14,R15 | R2512 | 4 | FRC2512F8200TS | FOJAN(富捷) | LCSC | C2999541 | 0.029 | 2
26 | 3.3kΩ | R18 | R0603 | 1 | 0603WAF3301T5E | UNI-ROYAL(厚声) | LCSC | C22978 | 0.002 | 2
27 | 5.6kΩ | R19 | R0603 | 1 | 0603WAF5601T5E | UNI-ROYAL(厚声) | LCSC | C23189 | 0.001 | 2
28 | TS-1187A-B-A-B | SW1 | SW-SMD_4P-L5.1-W5.1-P3.70-LS6.5-TL-2 | 1 | TS-1187A-B-A-B | XKB Connectivity(中国星坤) | LCSC | C318884 | 0.02 | 4
29 | TPS5430DDAR | U1 | ESOP-8_L4.9-W3.9-P1.27-LS6.0-TL-EP | 1 | TPS5430DDAR | TI(德州仪器) | LCSC | C9864 | 0.825 | 9
30 | ESP32-SOLO-1 | U2 | WIFIM-SMD_38P-L25.5-W18.0-P1.27 | 1 | ESP32-SOLO-1 | ESPRESSIF(乐鑫) | LCSC | C473005 | 3.926 | 39

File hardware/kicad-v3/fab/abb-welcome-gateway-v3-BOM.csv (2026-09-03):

Designator | Qty | Value | Footprint | Manufacturer Part | LCSC
C1 | 1 | 10nF | 0603B103K500NT | 0603B103K500NT | C57112
C2,C4 | 2 | 10uF | TAJA106K016RNJ | TAJA106K016RNJ | C7171
C3 | 1 | 68nF | CL10B683KB8NNNC | CL10B683KB8NNNC | C31658
C5 | 1 | 100nF | CC0603KRX7R9BB104 | CC0603KRX7R9BB104 | C14663
C6 | 1 | 100uF | TAJB107K006RNJ | TAJB107K006RNJ | C16133
C7,C8 | 2 | 2.2uF | CL31B225KBHNNNE | CL31B225KBHNNNE | C50254
C19 | 1 | RVT470UF16V67RV0031 | RVT470UF16V67RV0031 | RVT470UF16V67RV0031 | C2858857
C23 | 1 | VEJ101M1HTR-0810 | VEJ101M1HTR-0810 | VEJ101M1HTR-0810 | C176665
C_DCP1 | 1 | 22uF | capacitor_0805 | 22uF
C_DCP2 | 1 | 1uF | capacitor_0603 | 1uF
C_DCP3,C_U3 | 2 | 100nF | capacitor_0603 | 100nF
D1,D2,D3,D4,D5 | 5 | D | SS24 | SS24 | C7420362
D6,D7 | 2 | D | SD36C | SD36C | C502537
F2 | 1 | F2 | fuse | nSMD005 | C70064
FB1 | 1 | 0H | inductor_0805 | BLM21AG601SN1D
L1 | 1 | ACT45B-510-2P-TL003 | ACT45B-510-2P-TL003 | ACT45B-510-2P-TL003 | C76584
L2,L3 | 2 | SMMS0650-101M | SMMS0650-101M | SMMS0650-101M | C2894722
LED1 | 1 | KT-0603R | KT-0603R | KT-0603R | C2286
LED2,LED3 | 2 | 19-213_Y2C-CQ2R2L_3T | 19-213_Y2C-CQ2R2L_3T | 19-213_Y2C-CQ2R2L_3T | C72038
LED4 | 1 | 19-217_BHC-ZL1M2RY_3T | 19-217_BHC-ZL1M2RY_3T | 19-217_BHC-ZL1M2RY_3T | C72041
P1 | 1 | WJ500V-5.08-2P | WJ500V-5.08-2P | WJ500V-5.08-2P | C8465
P2 | 1 | 61300611121 | PinHeader_1x06_2.54mm | 61300611121
Q1,Q2,Q3 | 3 | S8050 | S8050 | S8050 | C2146
Q4,Q5,Q6 | 3 | 2N7002 | 2N7002 | 2N7002 | C8545
R1,R8,R9 | 3 | 100kΩ | resistor_res0603 | 100kΩ
R2,R3,R10 | 3 | 10kΩ | resistor_res0603 | 10kΩ
R4,R5,R6,R17 | 4 | 1kΩ | resistor_res0603 | 1kΩ
R7 | 1 | 75Ω | resistor_res0603 | 75Ω
R11,R16,R20 | 3 | 150Ω | resistor_res0603 | 150Ω
R12,R13,R14,R15 | 4 | 820Ω | FRC2512F8200TS | FRC2512F8200TS | C2999541
R18 | 1 | 3.3kΩ | resistor_res0603 | 3.3kΩ
R19 | 1 | 5.6kΩ | resistor_res0603 | 5.6kΩ
R_BGND,R_DGND,R_PGND | 3 | 0Ω | resistor_res0603 | 0Ω
SW1 | 1 | TS-1187A-B-A-B | TS-1187A-B-A-B | TS-1187A-B-A-B | C318884
TVS1 | 1 | D | SMBJ30A | SMBJ30A | C699005
U1 | 1 | TPS5430DDAR | TPS5430DDAR | TPS5430DDAR | C9864
U2 | 1 | ESP32-S3-WROOM-1-N16R8 | ESP32-S3-WROOM-1 | ESP32-S3-WROOM-1-N16R8 | C5736265
U3 | 1 | SN74LVC1G14DBVR | SOT-23-5 | SN74LVC1G14DBVR

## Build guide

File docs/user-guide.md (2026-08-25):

# User guide

How to install the ABB-Welcome gateway, flash it and integrate it with
Home Assistant.

> **Project status**: the hardware is finished at design level (not yet
> fabricated) and the firmware's bus protocol is still in development. Sections
> that depend on those steps are marked **[pending]**. See
> [STATUS.md](STATUS.md).

## 1. What it does

The gateway taps the 2-wire bus of an **ABB-Welcome / Busch-Welcome** door
intercom installation and exposes it to Home Assistant over WiFi (ESPHome):

- Notification when someone rings the doorbell.
- Remotely open the door from Home Assistant.
- Diagnostics (bus activity, device status).

It is powered directly from the intercom bus (~28 V) through an on-board buck
converter — no external supply needed.

## 2. Safety and compatibility

- The intercom bus carries roughly **28 V DC with data superimposed**. It is
  SELV, but treat it with care: disconnect the intercom power supply before
  wiring.
- Designed for 2-wire ABB-Welcome / Busch-Welcome installations. Other
  intercom families (TCS, Ritto, …) use different protocols and are **not**
  supported.
- The board connects **in parallel** with the existing indoor station wiring;
  it does not replace any component of the installation.

## 3. Connections

| Connector | Purpose |
|---|---|
| `P1` (screw terminal) | Intercom bus. `+` and `−` are marked on the silkscreen. The front-end tolerates brief reverse polarity, but connect it right: measure ~28 V DC between the wires and connect the positive one to `+`. |
| `P2` (6-pin header) | FTDI-style serial for the **first** flash: `GND · RTS · 3V3 · RX · TX · DTR`. Use a 3.3 V USB-serial adapter with RTS/DTR (auto-program supported). After the first flash, updates go over WiFi (OTA). |
| `RST` button | ESP32 reset. |

### LEDs

| LED | Meaning |
|---|---|
| `PWR` | 3V3 rail up. |
| `TX` | Gateway transmitting on the bus. |
| `RX` | Bus activity received. |
| `STAT` | Firmware status (GPIO6): **[pending]** blink codes will be documented with the firmware. |

## 4. First flash

1. Install [ESPHome](https://esphome.io) (`pip install esphome`).
2. Clone this repository and enter `firmware/esphome/`.
3. Copy `secrets.yaml.example` to `secrets.yaml` and fill in your WiFi
   credentials.
4. Connect the FTDI adapter to `P2` (do **not** connect the bus at the same
   time as the FTDI 3V3 — power the board from one source only).
5. Flash: `esphome run abb-welcome-gateway.yaml`.

After the first flash the device shows up in ESPHome/Home Assistant and can be
updated over the air.

## 5. Configure your installation

The protocol is handled by ESPHome natively, but the bus **addresses** and the
**door-opener secret** are specific to your installation. Find them once:

1. Flash the default config and open the logs (`esphome logs
   abb-welcome-gateway.yaml`). The `dump: [abbwelcome]` line prints every bus
   frame.
2. Ring the doorbell and open the door from an existing indoor station. Note the
   `source_address`, `destination_address`, `message_type` and `data` of the
   frames you see.
3. Edit `abb-welcome-gateway.yaml`: set the `substitutions` (indoor / outdoor /
   door-lock addresses) and the door-open `data` bytes in the
   `transmit_abbwelcome` action. Set `three_byte_address: "true"` if your
   addresses are 6 hex digits.
4. Re-flash (OTA is fine after the first flash).

See [protocol.md](protocol.md) for the message types and address conventions.

## 6. Home Assistant integration

With the ESPHome integration enabled, Home Assistant auto-discovers the device
and creates:

- `binary_sensor.doorbell` — pulses when the outdoor station calls.
- `button.open_door` — sends the door-open command.

Example automation (notification on ring):

```yaml
automation:
  - alias: "Doorbell notification"
    trigger:
      - platform: state
        entity_id: binary_sensor.doorbell
        to: "on"
    action:
      - service: notify.mobile_app_your_phone
        data:
          message: "Someone is at the door"
```

## 7. Installation on the bus

**[pending: photos of a real installation]**

1. Power down the intercom system.
2. Open the indoor station (or a junction box on the bus) and connect the two
   bus wires to `P1` respecting polarity.
3. Mount the board in a dry location away from mains wiring; keep the ESP32
   antenna edge clear of large metal surfaces.
4. Power the system back up: the `PWR` LED lights, and after a few seconds the
   device joins WiFi.

## 8. Troubleshooting

| Symptom | Check |
|---|---|
| No `PWR` LED | Bus voltage present at `P1`? Polyfuse `F2` may have tripped after a fault — it self-resets when power is removed. |
| Device not on WiFi | Serial logs via `P2` (`esphome logs`), check `secrets.yaml` credentials, antenna clearance. |
| No doorbell events | Check the `RX` LED blinks when the intercom is used (front-end OK). Then check the logs decode frames: if `dump: [abbwelcome]` shows nothing, try `inverted: true` on the receiver pin; if it shows frames, set the right addresses (section 5). |
| Door won't open | Confirm the door-open `data` bytes captured from a real unlock, and the destination address. TX polarity may need `inverted: true` on the transmitter pin. |

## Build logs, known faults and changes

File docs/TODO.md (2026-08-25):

# Pending tasks

Grouped roadmap towards a fabricated board running in Home Assistant.
See [STATUS.md](STATUS.md) for the current state of each area.

## Hardware (before ordering boards)

- [ ] Final visual review of the routed board in KiCad (silkscreen reference
      positions are still rough in places).
- [ ] Decide on the L2 / control-loop question: keep 100 µH (field-proven) or
      move to the datasheet recipe (~15 µH + 100–220 µF). If keeping 100 µH,
      plan a bench load-step measurement on the first prototype.
- [ ] Optional: upsize `C_DCP1` (22 µF 0805 → 1206 or 2 × 10 µF).
- [x] Export fabrication outputs from KiCad: Gerbers + drill, BOM and
      pick-and-place under `hardware/kicad-v3/fab/`.
- [ ] Fill the LCSC column for the generic passives / header in the BOM (basic
      parts, left blank to avoid guessing — see `fab/README.md`).
- [ ] Order prototypes (JLCPCB/PCBWay, 2-layer, 1 oz, ENIG).

## Firmware

Protocol done: ESPHome ships the `abbwelcome` remote protocol natively, so the
config uses it directly (documented in `docs/protocol.md`). Remaining work is
hardware-dependent:

- [ ] **Confirm logic polarity on the board**: the RX front-end ends in a
      Schmitt inverter (74LVC1G14) and TX is open-drain, so `remote_receiver` /
      `remote_transmitter` may need `inverted: true`. Verify with a real frame.
- [ ] **Discover addresses**: run with `dump: [abbwelcome]`, use the intercom,
      read source/destination addresses from the logs and set them in the YAML
      `substitutions`.
- [ ] **Door-opener secret**: capture a real door-open frame (or trial) and put
      its `data` bytes into the `transmit_abbwelcome` action.
- [ ] Optional entities: a `lock` instead of a plain button, diagnostic sensors
      (last message type, bus activity), 3-byte-address systems.
- [ ] End-to-end test against a real ABB-Welcome / Busch-Welcome installation.

## Validation (first prototype)

- [ ] Bring-up checklist: 3V3 rail, buck ripple, ESP32 boots, FTDI
      auto-program works.
- [ ] Buck load-step / thermal check under WiFi TX bursts.
- [ ] Bus capture session (logic analyzer on `BUS_RX_DIG`) to validate the
      front-end and the protocol implementation.

## Documentation

- [ ] Complete `docs/user-guide.md` once the protocol works end to end
      (photos of a real installation, HA screenshots).
- [ ] `docs/protocol.md` with the reverse-engineered bus protocol notes.
- [ ] Enclosure / mounting notes (DIN rail or wall box?).

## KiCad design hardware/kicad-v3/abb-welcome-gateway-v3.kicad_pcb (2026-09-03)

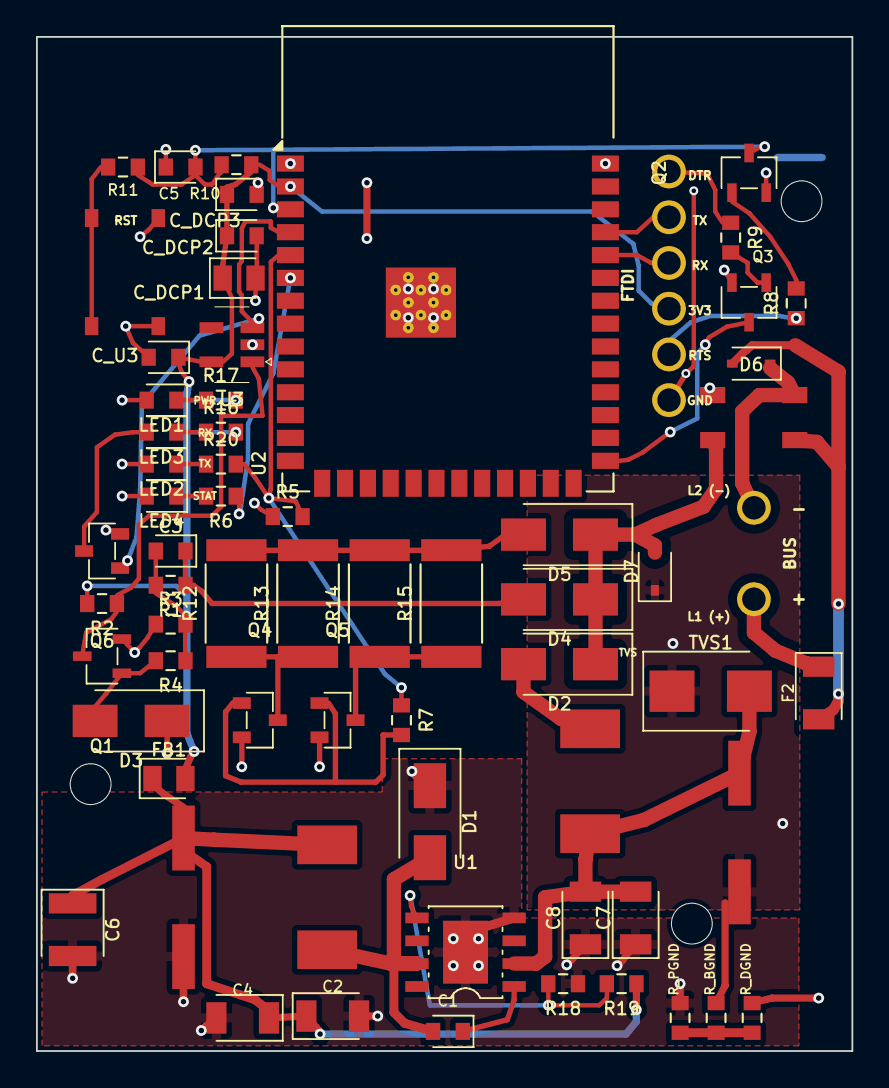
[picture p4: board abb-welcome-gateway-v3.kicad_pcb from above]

Board: 2 copper layers, 45.3 x 56.3 mm, 66 parts (0 on the bottom side), 40 nets.

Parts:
C1: 10nF; 0603B103K500NT
C2, C4: 10uF; TAJA106K016RNJ
C3: 68nF; CL10B683KB8NNNC
C5: 100nF; CC0603KRX7R9BB104
C6: 100uF; TAJB107K006RNJ
C7, C8: 2.2uF; CL31B225KBHNNNE
C19: RVT470UF16V67RV0031
C23: VEJ101M1HTR-0810
C_DCP1: 22uF; capacitor_0805
C_DCP2: 1uF; capacitor_0603
C_DCP3: 100nF; capacitor_0603
C_U3: 100nF; capacitor_0603
D1, D2, D3, D4, D5: D; SS24
D6, D7: D; SD36C
F2: F2; fuse
FB1: 0H; inductor_0805
L1: ACT45B-510-2P-TL003
L2, L3: SMMS0650-101M
LED1: KT-0603R
LED2, LED3: 19-213_Y2C-CQ2R2L_3T
LED4: 19-217_BHC-ZL1M2RY_3T
P1: WJ500V-5.08-2P
P2: 61300611121; PinHeader_1x06_2.54mm
Q1, Q2, Q3: S8050
Q4, Q5, Q6: 2N7002
R1, R8, R9: 100kΩ; resistor_res0603
R2, R3, R10: 10kΩ; resistor_res0603
R4, R5, R6, R17: 1kΩ; resistor_res0603
R7: 75Ω; resistor_res0603
R11, R16, R20: 150Ω; resistor_res0603
R12, R13, R14, R15: 820Ω; FRC2512F8200TS
R18: 3.3kΩ; resistor_res0603
R19: 5.6kΩ; resistor_res0603
R_BGND: 0Ω; resistor_res0603
R_DGND: 0Ω; resistor_res0603
R_PGND: 0Ω; resistor_res0603
SW1: TS-1187A-B-A-B
TVS1: D; SMBJ30A
U1: TPS5430DDAR
U2: ESP32-S3-WROOM-1-N16R8; ESP32-S3-WROOM-1
U3: SN74LVC1G14DBVR; SOT-23-5

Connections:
BOOT_CAP: C1.1, U1.1
BOOT_STRAP: Q3.3, U2.27
BUS_DC_RAW: D2.2, L3.1
BUS_FUSED: D6.2, F2.2, L1.1
BUS_GND: C23.2, D3.1, D7.1, L1.3, Q1.2, Q4.2, Q5.2, Q6.2, R3.1, R_BGND.1, TVS1.1
BUS_HOT: F2.1, P1.2
BUS_HOT_F: D2.1, D4.1, D5.1, D7.2, L1.4
BUS_PWR: C7.2, C8.2, C23.1, L3.2, TVS1.2, U1.2
BUS_RTN: D6.1, L1.2, P1.1
BUS_RX_A: C3.1, D4.2, R1.1
BUS_RX_BIAS: D3.2, Q1.1, R4.2
BUS_RX_DET: Q1.3, R2.1, U3.1
BUS_RX_FILT: C3.2, R1.2, R3.2, R4.1
BUS_RX_PIN: Q6.1, U2.4, U3.3
BUS_TX: D5.2, R12.2, R13.2, R14.2, R15.2
BUS_TX_PIN: R5.2, R7.1, R20.2, U2.5
D0_DRIVE: Q3.1, R9.2
DGND: C5.1, C_DCP1.2, C_DCP2.2, C_DCP3.2, C_U3.2, LED1.2, LED2.2, LED4.2, P2.1, Q2.2, Q3.2, R5.1, R_DGND.1, SW1.3, SW1.4, U2.1, U2.40, U2.41, U3.2
DTR: P2.6, R9.1
EN: C5.2, Q2.3, R10.1, R11.2, U2.3
EN_DRIVE: Q2.1, R8.2
FB_TAP: R18.2, R19.2, U1.5
GND: R_BGND.2, R_DGND.2, R_PGND.2
LED_PIN: R6.2, U2.6
PGND: C2.2, C4.2, C6.2, C7.1, C8.1, C19.2, D1.1, R18.1, R_PGND.1, U1.4, U1.9
PWR_LED_A: LED1.1, R17.1
RST_BTN: R11.1, SW1.1, SW1.2
RTS: P2.2, R8.1
RX: P2.4, U2.36
RX_LED_A: LED3.1, R16.1
RX_LED_K: LED3.2, Q6.3
STAT_LED_A: LED4.1, R6.1
SW_NODE: C1.2, D1.2, L2.1, U1.7
TX: P2.5, U2.37
TX_DRAIN_A: Q4.3, R12.1, R13.1
TX_DRAIN_B: Q5.3, R14.1, R15.1
TX_GATE: Q4.1, Q5.1, R7.2
TX_LED_A: LED2.1, R20.1
V3V3: C2.1, C4.1, C6.1, C19.1, FB1.1, L2.2, R19.1
V3V3_ESP: C_DCP1.1, C_DCP2.1, C_DCP3.1, C_U3.1, FB1.2, P2.3, R2.2, R10.2, R16.2, R17.2, U2.2, U3.5

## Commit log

2026-06-13 Evolucion del diseno: ESP32-S3-WROOM-1, nuevos imports y generador de chips
    - output/: migracion a ESP32-S3-WROOM-1, buffer Schmitt, islas de GND
    (PGND/DGND/BUS_GND), bead + desacoplo en 3V3, terminacion de bus
    - nuevos imports: ESP32_S3_WROOM_1, MOSFET_2N7002, BJT_S8050; ajustes en TPS5430
    - tools/generate-import.mjs: generador de wrappers de chip
    - README: estado de diseno y revision pendiente antes de fabricacion
    - samples/ y configs actualizados
2026-06-13 Arreglo del front-end de RX, F2 como fuse y reorganizacion del repo
    - RX: separar BUS_RX_A (nodo de ~bus) de BUS_RX_DET (salida colector de Q1
    con pull-up R2 a V3V3_ESP). La entrada del Schmitt 74LVC1G14 ya no cuelga
    del nodo de alta tension; queda dentro de su abs-max (VCC+0.5V)
    - F2 polyfuse modelado como <fuse> en vez de <chip> (currentRating no era
    prop valida de chip; tsc --noEmit ahora pasa limpio)
    - mover fuente EasyEDA v2 + circuit.json a hardware/easyeda-v2/; repuntar
    rutas en tools/ via constante SRC_DIR
    - actualizar rutas en README.md
    [BOM.csv]
2026-06-13 Actualizar README: estado real v3.0 y tension de bus para TVS1
    - reescribir 'Known issues': los bugs de conectividad v2.x ya estan
    arreglados; documentar lo que queda
    - TVS1: el bus ABB-Welcome es 28V +-2V (controlador 28VDC), asi que
    SMBJ24CA (standoff 24V) conduce en operacion normal -> usar SMBJ30A,
    con la nota del compromiso clamp 48V vs abs-max 36V del TPS5430
    - mover RX/TX/divisor/F2/R_TERM/SW1 a la seccion 'Fixed in v3.0'
2026-06-13 TVS1 a SMBJ30A, pin de versiones, check de nets colgantes y CI
    - TVS1: SMBJ24CA -> SMBJ30A (unidireccional, catodo a BUS_PWR). El bus es
    28V +-2V, asi que el standoff de 24V conducia en operacion normal
    - output/package.json: pinear circuit-json 0.0.425 y tscircuit 0.0.1747
    (estaban en 'latest')
    - tools/check-dangling-nets.mjs: detecta nets con un solo pin en
    index.circuit.tsx; 'npm run check' y encadenado en 'npm run validate'
    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
2026-06-13 README: verificacion de L2 contra el datasheet del TPS5430
    100uH esta dentro del rango 10-100uH del datasheet (SLVS632L), pero con
    ~590uF de bulk el cruce del lazo (~1.5kHz) cae por debajo de la ventana
    3-30kHz de TI: estable pero lento, apoyado en la ESR del bulk. Avisos:
    no cambiar a ceramicos sin red de compensacion externa; alternativa
    L=15uH/100-220uF para cruce de libro
2026-06-13 Proceso: versionar package-lock y usar npm ci en CI
    - dejar de ignorar output/package-lock.json y versionarlo (regenerado con
    las versiones pineadas) para instalaciones reproducibles
    - CI: npm ci en vez de npm install (deterministico, mas rapido)
    - README: lock+npm ci movido a 'tooling in place'; snapshots quedan
    pendientes (necesitan binario nativo de resvg, mejor en la maquina dev)
2026-06-13 ESP32_S3_WROOM_1: schPinArrangement para esquematico legible
    Coloca solo los 9 pines que usa la placa (V3V3/EN arriba, GND abajo,
    RXD0/GPIO4 a la izquierda, TXD0/GPIO5/GPIO2/GPIO0 a la derecha) en vez de
    los 61. El resto siguen como puertos para el PCB. Verificado con
    @tscircuit/eval headless: el simbolo pasa de 61 a 9 puertos; tsc limpio.
    README: schPinArrangement marcado como hecho; anotado el
    pcb_autorouting_error visto durante el eval como pendiente de proceso.
2026-06-13 Export v3 a KiCad para rutear (hardware/kicad-v3/)
    El autorouter de tscircuit no converge en esta placa (sin terminar a 100x)
    y no hace pours, que este diseño necesita (islas GND, RF, potencia, bus HV).
    Se exporta el diseño v3 a KiCad via circuit-json-to-kicad:
    - .kicad_pcb: 66 footprints colocados, 218 pads, 200 nets, contorno; sin
    pistas (a rutear en KiCad)
    - .kicad_sch (216 simbolos) y .kicad_pro
    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
    [abb-welcome-gateway-v3.kicad_pcb, abb-welcome-gateway-v3.kicad_sch]
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2026-08-24 KiCad 9: re-guardado del proyecto v3 en formato nativo (baseline pre-ruteo)
    [abb-welcome-gateway-v3.kicad_sch]
2026-08-24 PCB v3: footprint real del ESP32-S3-WROOM-1, placa a 56.4mm y placement listo para rutear
    - U2: sustituido el footprint tipo QFN invalido (61 pads inventados) por
    RF_Module:ESP32-S3-WROOM-1 oficial de KiCad; nets remapeados a los pines
    reales del modulo (GND/3V3/EN/IO4/IO5/IO0/RXD0/TXD0/IO2 + EP). Antena al
    borde superior con su keep-out.
    - Contorno: +3mm de alto (45.4x56.4) para dar sitio a la banda del buck.
    - Placement reorganizado por islas de tierra: DGND arriba (ESP32/FTDI/reset/
    LEDs/U3), BUS_GND banda media y columna derecha (front-end RX/TX, entrada
    28V), PGND abajo (buck TPS5430 con U1 rotado 180: VIN hacia C7/C8, SW
    hacia D1/L2; feedback R18/R19 junto al pin FB; C4/C6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
    [abb-welcome-gateway-v3.kicad_pcb]
2026-08-24 PCB v3: reglas de diseno, net classes y zonas de las 3 islas de GND
    - .kicad_pro: minimos 0.2/0.2mm (JLCPCB 2 capas), via 0.6/0.3; clases
    Power (0.8mm), BusHV (0.8mm ancho, 0.5mm clearance para el bus 28V),
    Ground (0.5mm) con asignacion por net.
    - Zonas B.Cu: plano DGND (superior + corredor por el borde este hasta el
    star point), banda BUS_GND (front-end + bolsillo de entrada de bus),
    plano PGND (banda inferior del buck). Separacion 0.3mm entre islas.
    - Zonas F.Cu: refuerzo PGND (termico del buck) y BUS_GND en el bolsillo.
    - El keep-out de antena del modulo mantiene sin cobre la franja superior.
    [abb-welcome-gateway-v3.kicad_pcb]
2026-08-25 PCB v3: cosido de tierras y ruteo del buck (bloque 1)
    - Vias de cosido a plano para todos los pads GND SMD (DGND/BUS_GND/PGND),
    EP del modulo y del TPS5430 con 4 vias cada uno.
    - Buck ruteado: VIN (L3->C7/C8->pin2), SW (L2/D1/C1->pin7), bootstrap,
    feedback por B.Cu hasta R18/R19, y distribucion V3V3 (C19/C6/C4/C2/FB1
    y cruce B.Cu hasta R19). Zonas con frontera oeste BUS_GND/PGND ajustada
    y extension norte del bolsillo para la via de L1.3.
    - DRC: 0 errores electricos.
    [abb-welcome-gateway-v3.kicad_pcb]
2026-08-25 PCB v3: ruteo columna ESP32, entrada de bus 28V y front-end RX (bloque 2)
    - Columna izquierda del modulo: entradas de pines 2-5 resueltas (V3V3_ESP
    desde R10.2, EN por dorsal B.Cu con via pegada al pad, BUS_RX_PIN en
    zigzag por el hueco de los desacoplos, via-en-pad para GND del modulo).
    - Bus 28V: BUS_HOT/BUS_FUSED con salto B.Cu por el corredor este,
    BUS_RTN, cadena BUS_HOT_F en linea recta por la pila D5/D4/D2+D7,
    BUS_DC_RAW a L3 y BUS_PWR TVS1/C23. TVS1 medio paso al oeste.
    - Front-end RX completo: BUS_RX_A (carril bajo las 2512), FILT/BIAS/DET
    (DET cruza en diagonal hasta U3), RX_LED_K.
    - DRC: 0 errores.
    [abb-welcome-gateway-v3.kicad_pcb]
2026-08-25 PCB v3: LEDs, reset, tronco V3V3_ESP y cadena TX (bloque 3a)
    - LEDs girados 180: catodos al oeste con vias DGND en campo abierto,
    anodos enfrentados a sus resistencias.
    - Tronco V3V3_ESP por B.Cu (FB1 -> cluster norte) con ramas a R16/R17
    (via en pad), C_U3/U3.5, R2.2 y enlace del cluster por el hueco de U3.
    - BUS_RX_PIN hasta Q6.1 por B.Cu; BUS_TX_PIN completo (canal oeste,
    junction y salto B a R7); TX_GATE rodeando por el sur; drenadores
    y BUS_TX en lineas rectas por los huecos de las 2512.
    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
    [abb-welcome-gateway-v3.kicad_pcb]
2026-08-25 PCB v3: ruteo completo — DRC limpio y ratsnest a cero
    - Lado derecho: BOOT_STRAP, RTS (R8 movido junto al taladro, via en pad),
    DTR, EN_DRIVE, D0_DRIVE, UART RX/TX, BUS_HOT_F v2 y puente GND del star.
    - LED_PIN reasignado del pin 38 (IO2) al pin 6 (IO6) del modulo: el
    cuadrante de P2 es intransitable (anillos THT cada 2.54mm); con IO6 la
    ruta queda en B.Cu directa a R6. EL FIRMWARE DEBE USAR GPIO6.
    - V3V3_ESP a P2.3 desde via-en-pad del pin 2 por carril B bajo el modulo.
    - Puentes DGND para reunificar el plano B (franja bajo modulo y zona este
    selladas por la dorsal EN y los anillos de P2).
    - kicad-cli drc: 0 errores, 0 unconnected.
    [abb-welcome-gateway-v3.kicad_pcb]
2026-08-25 PCB v3: serigrafia (titulos al lado B, tamanos normalizados) y READMEs
    Documentadas las divergencias del PCB ruteado respecto a la fuente
    tscircuit: footprint oficial del modulo, LED de estado en GPIO6 (cambio
    necesario en firmware), placa 45.4x56.4, recolocaciones por islas.
    [abb-welcome-gateway-v3.kicad_pcb]
2026-08-25 Reorganizacion: historial de diseno congelado en legacy/
    - hardware/easyeda-v2 -> legacy/easyeda-v2 (fuente v2 original, mat931)
    - output -> legacy/tscircuit (captura esquematica v3, congelada tras el
    export a KiCad)
    - tools -> legacy/tools y samples -> legacy/samples (pipeline de conversion
    EasyEDA->tscircuit; rutas internas actualizadas a la nueva ubicacion)
    - prompt_ia_helper.md -> legacy/tscircuit-primer.md
    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
    [BOM.csv]
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2026-08-25 Firmware: esqueleto ESPHome con componente externo abb_welcome
    - abb-welcome-gateway.yaml: ESP32-S3 + esp-idf, API/OTA/WiFi, status LED
    en GPIO6, hub del bus en GPIO4 (RX) / GPIO5 (TX).
    - components/abb_welcome/: hub con captura de flancos por ISR (base del
    decodificador), binary_sensor de timbre y button de abrepuertas.
    El protocolo del bus queda como siguiente tarea (docs/TODO.md).
    - secrets.yaml.example + secrets.yaml ignorado.
    - Verificado: esphome config valido y esphome compile correcto (IDF 5.5.4).
2026-08-25 CI: DRC de KiCad y compilacion del firmware ESPHome
    Sustituye los checks del pipeline tscircuit (ahora en legacy/) por:
    - pcb-drc: kicad-cli pcb drc en contenedor kicad/kicad:9.0.2, falla con
    cualquier violacion de severidad error.
    - firmware: esphome compile con secrets de ejemplo y cache del toolchain.
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2026-08-25 PCB v3: serigrafia — refs dentro del borde + autor y fecha
    - Reubicadas al interior las referencias que se salian del contorno:
    C1/C2/C4 y las tres 0R del star point (R_PGND/R_BGND/R_DGND) al norte de
    su componente; R10/R11/C5 fuera de la franja de antena; F2/Q3 hacia dentro.
    Verificado: 0 referencias fuera del borde.
    - Anadido en la cara inferior (B.SilkS): github.com/fquinto y nov-2026,
    bajo el titulo existente.
    - DRC electrico intacto (0 errores, 0 unconnected). Render top actualizado.
    [abb-welcome-gateway-v3.kicad_pcb]
2026-08-25 PCB v3: salidas de fabricacion (Gerbers, taladros, BOM, pick-and-place)
    - fab/abb-welcome-gateway-v3-gerbers.zip: gerbers RS-274X (2 capas + mascara,
    pasta, serigrafia) + taladro Excellon, listo para el fabricante.
    - fab/gerbers/: capas individuales navegables + mapa de taladros.
    - fab/abb-welcome-gateway-v3-BOM.csv: BOM agrupado (66 componentes, 38 lineas)
    con MPN y LCSC del diseno; pasivos genericos y header sin LCSC (basic parts,
    a asignar en el ensamblado — sin adivinar para no montar la parte erronea).
    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
    [abb-welcome-gateway-v3-BOM.csv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]
2026-08-25 PCB v3: ajuste de serigrafia y regeneracion de gerbers
    - Reubicadas etiquetas de los desacoplos (C_DCP1/2/3, C_U3) y varias mas
    para legibilidad; todas dentro del contorno, DRC limpio.
    - Gerbers, taladro y pick-and-place regenerados desde este estado para que
    el paquete de fabricacion coincida con el PCB. Render superior actualizado.
    [abb-welcome-gateway-v3-B_Cu.gbr, abb-welcome-gateway-v3-B_Mask.gbr, abb-welcome-gateway-v3-B_Paste.gbr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]
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2026-08-27 analysis: add TPS5430 buck loop (Bode) and TVS clamp pre-fab verification
    Numerical loop-stability model calibrated to the datasheet worked example, plus a TVS clamp-vs-abs-max check. Refines the pre-fabrication notes in docs/STATUS.md.
2026-09-03 fab: specify exact parts for P2 (1x6 2.54mm header) and U3 (SN74LVC1G14DBVR)
    Both carried generic placeholders from the tscircuit conversion. Set the
    manufacturer part in the symbol Value + footprint identity in schematic and
    PCB, and refresh the BOM/pos exports. Metadata only; no copper change, DRC
    still 0 errors / 0 unconnected. Documented in docs/STATUS.md.
    [abb-welcome-gateway-v3-BOM.csv, abb-welcome-gateway-v3.kicad_pcb, abb-welcome-gateway-v3.kicad_sch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]
2026-09-04 docs: mark P2/U3 BOM parts resolved and confirmed by fab
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
